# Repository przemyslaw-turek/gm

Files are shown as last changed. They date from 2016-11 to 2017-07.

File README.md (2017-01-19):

# GRANDMA MONITOR - electronic part

## I. Description
<OL>
<P style="line-height: 1cm; ">Grandma monitor is a system created to monitor conditions inside of old person's flat.
The system uses diffrent sensors to collect informations about movement, temperature etc. and send it via internet to protector. 
Main controler (Raspberry Pi 3) is connected with big red button, which turn on panic alarm (on protectors mobile device).
Except Raspberry Pi we use also ESP8266 which supports whireless communication and enables placement of sensors in the other part of the flat. </P>
</P>
<P style="line-height: 1cm; ">Befor you begin instalation you need to decide which sensors you want to use and where to put them.
Here is the list of the sensors that we support:</P>
<LI> MQ-2 Semiconductor Sensor for Combustible Gas  </LI>
<LI> PIR HC-SR501 Motion Sensor </LI>
<LI> DS18B20 Temperature Sensor </LI>
<LI> DHT11 Humidity & Temperature Sensor</LI>
<LI> Reed relay</LI>
</OL>

## II. Instalation
<OL>
<P style="line-height: 1cm; ">
The electronic part of the project is divided into three main parts:
</P>
<LI> Raspberry PI 3	(master controller) </LI>
<LI> ESP8266	(slave controller) </LI>
<LI> Sensors </LI>
<P style="line-height: 1cm; ">

</P>
<P style="line-height: 1cm; ">
In each of this parts you can find the manual.
</P>

</OL>

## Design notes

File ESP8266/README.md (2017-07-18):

<html>
<h1>#ESP8266 configuration</h1>
<li>If you are using ESP8266 with NodeMcu dev board just plug in to USB using micro USB (there is already USB to UART RS232 converter on board). If yours computer didn’t see ESP you may need to install CH340 Driver </li>
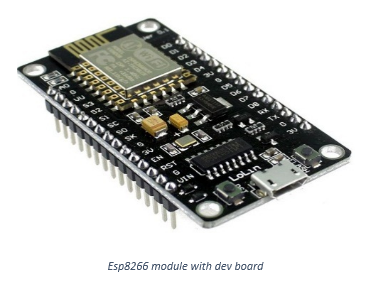
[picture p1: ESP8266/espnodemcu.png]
ESP with NodeMcu board

After that download and install Arduino IDE (at least 1.6.4 version).<br>
Create subfolder “portable” in Arduino folder. Then open File->Preferences , in Additional Boards Manager URL’s paste: <b>http://arduino.esp8266.com/stable/package_esp8266com_index.json</b><br><br>
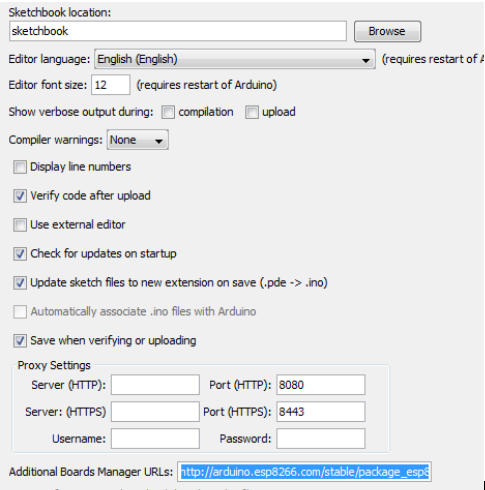
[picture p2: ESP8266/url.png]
boardmanager
<br>
<br>
Then in Tools->Board->Boards Manager install esp8266 package<br>

package<br>
<br>
To add libraries in Arduino IDE: Sketch -> Include library ->Manage libraries type the library you need and add it.<br><br>

Libraries used in project: <br>
-Adafruit<br>
-DHT<br>
-DHT_U<br>
-ESP8266WiFi<br>
-PubSubClient<br>
<br>
It is not possible to add Adafruit library to libraries in Arduino. It is need to download this library direct from Github repository. 

To upload program in Arduino  in Tools you need to choose Board (depends on ESP version, for example Generic ESP module), upload speed 115200.<br><br>

To check your connection with raspberry pi (broker) upload code from ESP8266_wifi_mqtt.ino.  <br>
For debug you can use serial monitor (Tools -> Serial monitor).

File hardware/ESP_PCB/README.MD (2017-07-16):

<b>PCB for ESP8266</font></b><br />
<br />
I. BASIC VERSION:
<br />
<br />
Necessery elements:
<br />
<ul>
<li>ESP 8266</li>
<br />
<li>7x Screw terminals 3-Pin 3,5mm - https://botland.com.pl/zlacza-ark/2555-zlacze-ark-raster-35-mm-3-pin-.html</li>
<br />
<li>Level shifter - http://allegro.pl/modul-konwerter-poziomow-3-3v-5v-stanow-log-i4973044836.html</li>
<br />
</ul>

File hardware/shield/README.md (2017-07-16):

<b>Raspberry Pi 3 Shield</font></b><br />
<br />
I. BASIC VERSION:
<br />
<br />
Necessery elements:
<br />
<ul>
<li>7x Screw terminals 3-Pin 3,5mm - https://botland.com.pl/zlacza-ark/2555-zlacze-ark-raster-35-mm-3-pin-.html</li>
<br />
<li>Female goldpin header 2x40 2,54mm - https://botland.com.pl/gniazda-szpilkowe-goldpin/1104-listwa-zeska-2x40.html</li>
<br />
<li>Level shifter - http://allegro.pl/modul-konwerter-poziomow-3-3v-5v-stanow-log-i4973044836.html</li>
<br />
</ul>

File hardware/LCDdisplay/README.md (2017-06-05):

<h1> LCD display </h1>
<h2> 1. Connection diagram</h2>
Pictrue
 
<h2> 2. Components</h2>
<ol>
<li>ESP8266 Lolin </li>
<li>Voltage converter(SPF-02259)</li>
<li>I2C converter(LCD-02352)</li>
<li>LCD display(2x16)</li>
</ol>

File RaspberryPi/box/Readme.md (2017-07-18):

<h1>Casing</h1>
File: <b>pudelko2-1.stl</b> is a three-dimensional design of the RaspberryPi microprocessor casing.
Just check the dimensioning and the file is suitable for direct 3D printing.

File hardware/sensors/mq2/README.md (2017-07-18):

<html>
<h1>#Smoke detector and flammable gases MQ-2 sensor </h1>
<li>Wiring diagram</li>
Diagram
<li>	The necessary elements</li><br>
      1.	ESP 12e nodemcu v3

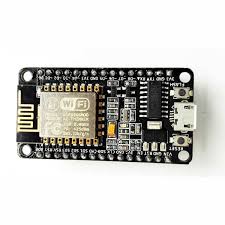
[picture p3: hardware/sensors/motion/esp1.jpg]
ESP
 <br>
 ESP<br>
      2. Bc557 NPN1<br>
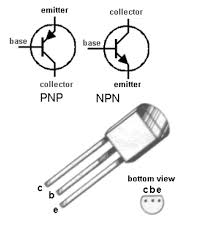
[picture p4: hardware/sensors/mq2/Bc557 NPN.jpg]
NPN
      <br>
      3. Voltage source (5V)<br>
4. MQ-2<br>
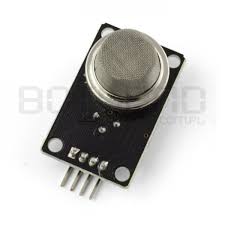
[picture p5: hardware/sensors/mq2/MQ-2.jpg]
mq2
<br>
5. Resistor(4.7kΩ)<br>
6. GPIO 14(D5)<br>
7. Wiring diagram<br>

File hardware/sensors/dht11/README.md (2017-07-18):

<html>
<h1>#Temperature and humidity sensor DHT11 </h1>
<li>Wiring diagram</li>
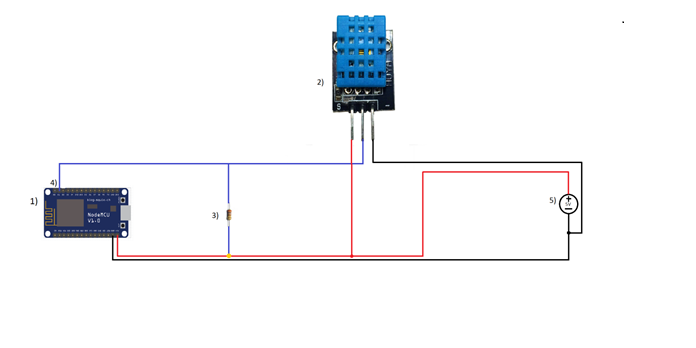
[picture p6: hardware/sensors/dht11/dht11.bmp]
Diagram

<li>	The necessary elements</li><br>
      1.	ESP 12e nodemcu v3

 ESP<br>
 ESP<br>
      2. DHT11<br>
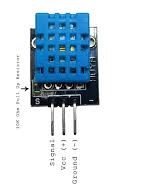
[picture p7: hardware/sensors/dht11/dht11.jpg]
DHT
      <br>
     3. Resistor 4.7kΩ <br>
      4. GPIO5(D1)  <br>
      5. Voltage source(5V)

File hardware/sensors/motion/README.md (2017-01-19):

<html>
<h1>#PIR-HC-SR501 Motion sensor </h1>
<li>Wiring diagram</li>
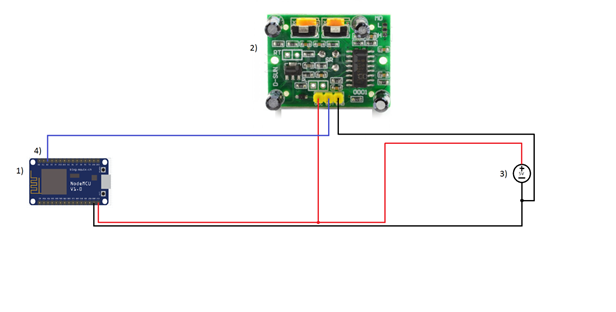
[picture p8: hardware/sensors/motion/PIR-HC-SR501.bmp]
Diagram

<li>	The necessary elements</li><br>
      1.	ESP 12e nodemcu v3

 ESP<br>
 ESP<br>
      2. PIR HC-SR501<br>
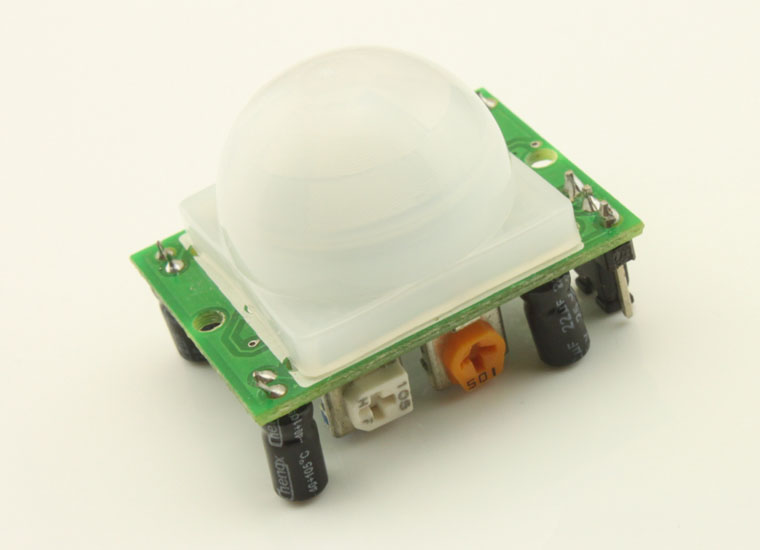
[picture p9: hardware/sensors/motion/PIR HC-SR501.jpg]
PIR
      <br>
      3.	Voltage source(5V)<br>
      4.	GPIO 4(D2)<br>

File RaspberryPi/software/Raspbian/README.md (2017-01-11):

# Installation of Raspbian 

## I. Software

#### 1. Download Raspbian:
   https://www.raspberrypi.org/downloads/raspbian/
#### 2. Download Putty:
   http://www.chiark.greenend.org.uk/~sgtatham/putty/download.html 
#### 3. Download RUFUS:
   https://rufus.akeo.ie/?locale=pl_PL 

## II. SSH Server

<OL>
<LI> Unpack file with Raspbian's image </LI>
<LI> Format microSD card </LI>
<LI><P> Use Rufus to install Raspbian on card. Use settings as in the picture below: </P>
<P> (Button in red frame is used to select the path to Raspbian's image.) </P>
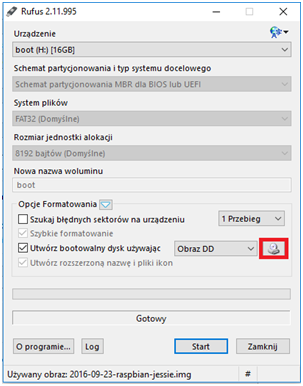
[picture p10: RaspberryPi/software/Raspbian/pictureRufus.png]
</LI> 

<LI> Press "Start". </LI>
<LI> Open your memory card and create new file "ssh" in main folder. Make sure that it hasn't got filename extension. </LI>
<LI> Place the memory card in the Raspberry </LI>
<LI> Connect Raspberry with router using ethernet cable </LI>
<LI> Connect the supply to the Raspberry </LI>
<LI><P> Check Raspberry's IP address in router </P>
Pictrue</LI>
<LI> Run Putty </LI> 
<LI> In field Host Name - type Raspberry's IP address </LI>
<LI><P> Press "Open" </P>
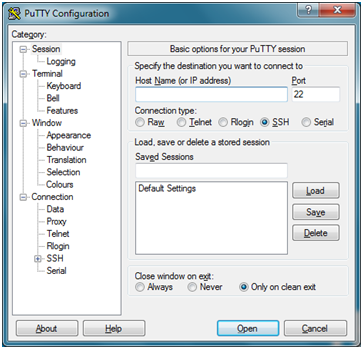
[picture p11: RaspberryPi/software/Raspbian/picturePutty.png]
</LI>
<LI><P> Press "Yes" </P>
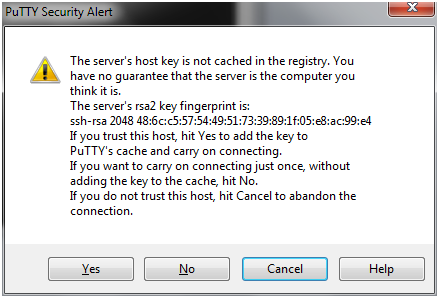
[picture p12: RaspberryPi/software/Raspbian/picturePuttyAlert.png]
</LI>
<LI><P> Default login: "pi" </P>
<P> Default password: "raspberry" </P></LI>

</OL>

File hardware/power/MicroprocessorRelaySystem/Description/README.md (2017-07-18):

Microprocessor relay system
Through this arrangement we have the ability to control devices powered by alternating current.
In order to realize this layout you have to combine elements according to the schematic.
You can prepare the chip yourself, or use a pcb board design.
Please upload to esp8266 prepared program in Arduino IDE.
If you upload a program and specify good network parameters you should get the following form of serial port monitor:
 
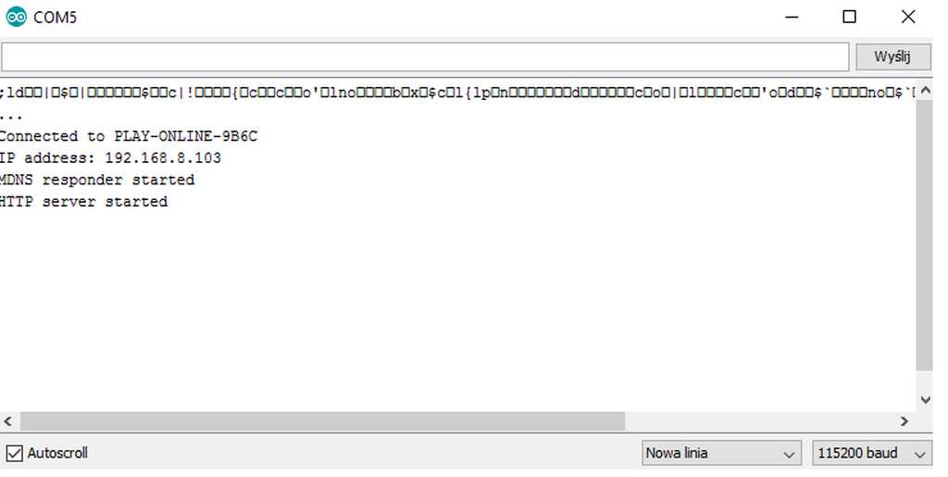
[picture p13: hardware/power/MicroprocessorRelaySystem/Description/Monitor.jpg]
 
Open the Arduino serial monitor at a baud rate of 115200. 
After a few seconds your IP address should appear.

Open any browser from a device that is connected to the same router that your ESP is. Then type the IP address and click Enter!

You should see the following image:
 
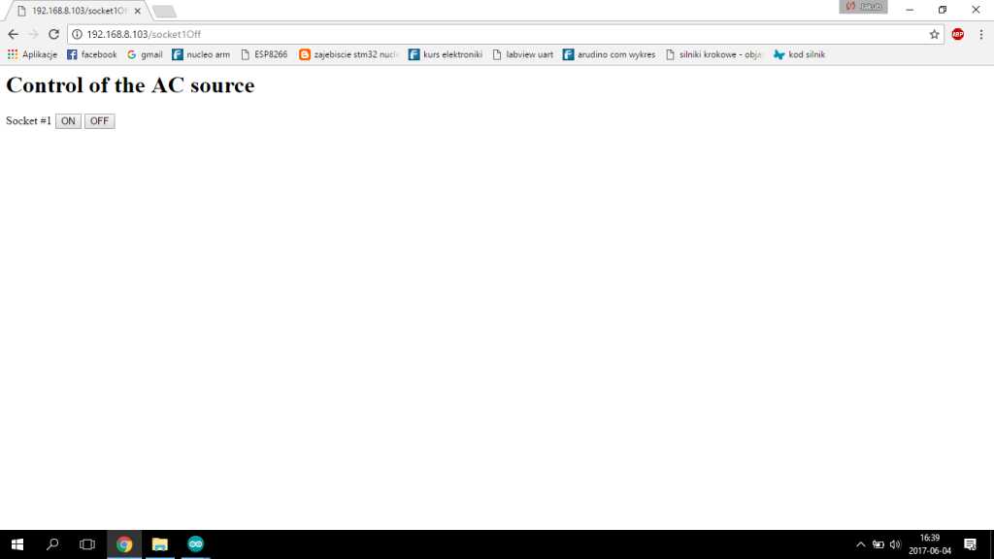
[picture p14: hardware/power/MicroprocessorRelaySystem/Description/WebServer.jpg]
 
Now when you press the buttons in your web server you can control any device connected!!!

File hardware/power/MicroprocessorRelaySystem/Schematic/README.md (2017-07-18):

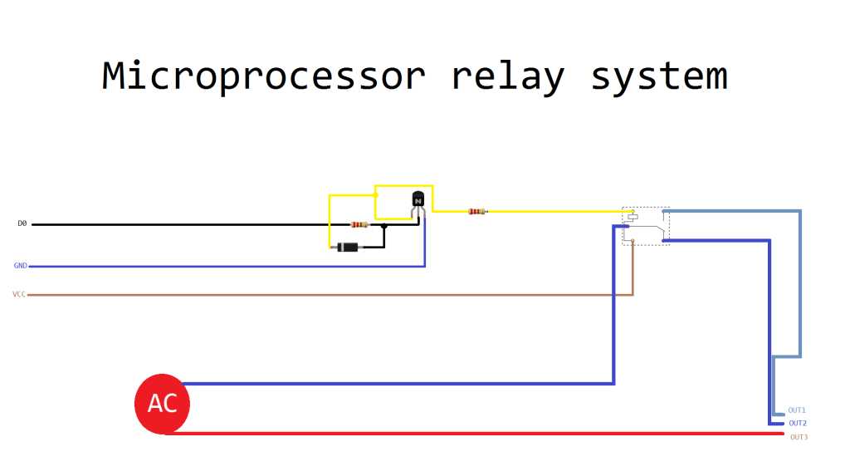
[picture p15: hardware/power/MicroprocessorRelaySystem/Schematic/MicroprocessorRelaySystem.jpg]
Pictrue
  
<li>Components</li>

1. ESP8266 Lolin
2. Transistor npn(C3274D)
3. Relays(36.11-4011)
4. Diode(4007)
5. Resistor 220 Ohm
6. Resistor 
7.Screw connection
 
 VCC and GND for 3,3V voltage;
 AC- Sinusoidal power supply

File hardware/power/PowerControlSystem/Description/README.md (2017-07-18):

<h1>Power Control System</h1>
This chip was created to make our microprocessor powered at all times. In case of power failure, the system should be powered from Power Bank. When Power bank is charging does not give the output voltage.

You need to do one of three layouts. The first one is easier to implement and the second one does not disturb the operation of the control device. The third circuit is the simplest and does not use ADC.
The fourth system is designed for advanced electronics. For this layout we have not prepared the program code. It is shown for illustrative purposes

<b>If you use the third  chip, you will need to use 0 GPIO to control the power supply!!!!</b>

If you use the first chip, you will need to use 3 GPIO to control the power supply(A0,D5 and D6).

In turn, using the second scheme will suffice with two pins(A0 and D5).

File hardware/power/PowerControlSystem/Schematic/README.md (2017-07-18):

<u><h1><b>&nbsp;&nbsp;&nbsp;&nbsp;&nbsp;&nbsp;&nbsp;&nbsp;&nbsp;&nbsp;&nbsp;&nbsp;&nbsp;&nbsp;&nbsp;&nbsp;&nbsp;&nbsp;&nbsp;&nbsp;&nbsp;&nbsp;&nbsp;&nbsp;&nbsp;&nbsp;&nbsp;&nbsp;&nbsp;&nbsp;&nbsp;&nbsp;Power control system</b></h1></u>

<b>I version</b>

<li>Connection diagram</li>

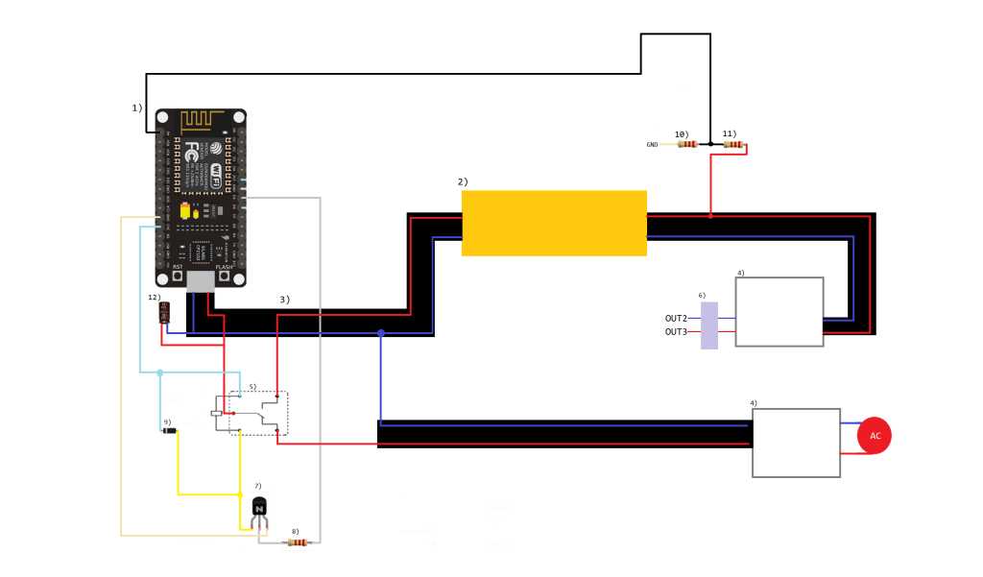
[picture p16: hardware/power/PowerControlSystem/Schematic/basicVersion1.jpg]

 
<li>Components</li>

1. ESP8266 Lolin					
2. Power bank(5V)					
3. USB cable						
4. Power supply					
5. Relay(3.3-5V)
6. Screw connection
7. Transistor npn(C3274D)
8. Resistor(100 Ohm)
9.   Diode(4007)
10. Resistor(2200 Ohm)
11. Resistor(1200 Ohm)
13. Electrolytic capacitor(47 uF)

<b>II version</b>

<li>Connection diagram</li>

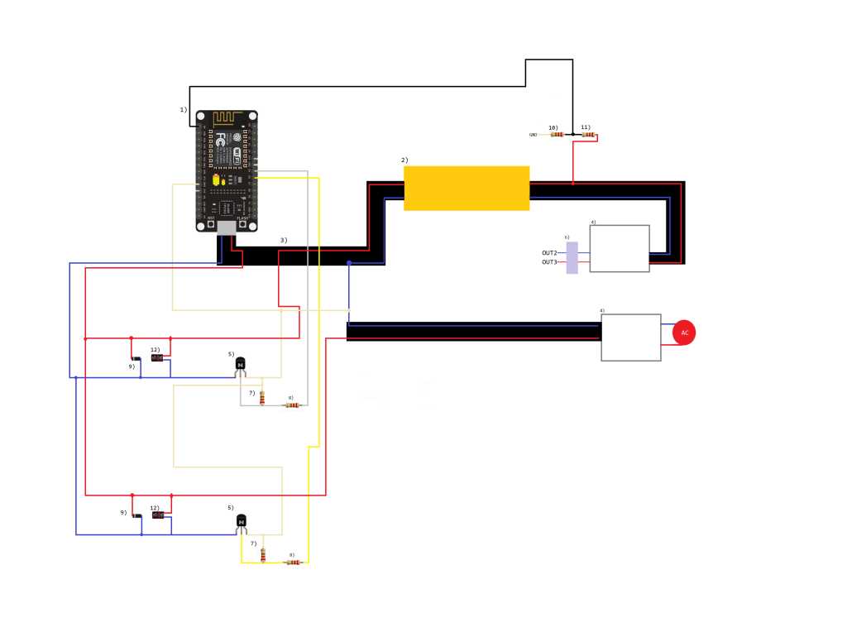
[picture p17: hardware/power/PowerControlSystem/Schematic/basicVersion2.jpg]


<li>Components</li>

1. ESP8266 Lolin					
2. Power bank(5V)					
3. USB cable						
4. Power supply					
5. Transistor npn(C3274D) 
6. Screw connection
7. Resistor( 2200 Ohm)
8. Resistor( 100 Ohm)
9.   Diode(4007)
10. Resistor(2200  Ohm)
11. Resistor(1200 Ohm)
12. Electrolytic capacitor(47 uF)

<b>III version</b>

<li>Connection diagram</li>

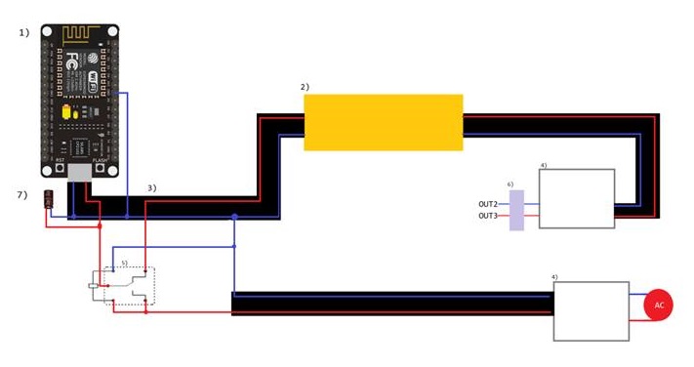
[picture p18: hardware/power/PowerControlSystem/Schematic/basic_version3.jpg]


<li>Components</li>

1. ESP8266 Lolin					
2. Power bank(5V)					
3. USB cable						
4. Power supply			
5. Relay(3.3-5V)
6. Screw connection
7. Electrolytic capacitor(47 uF)

<b>IV version</b>

<i>Extended version</i>

<li>Connection diagram</li>

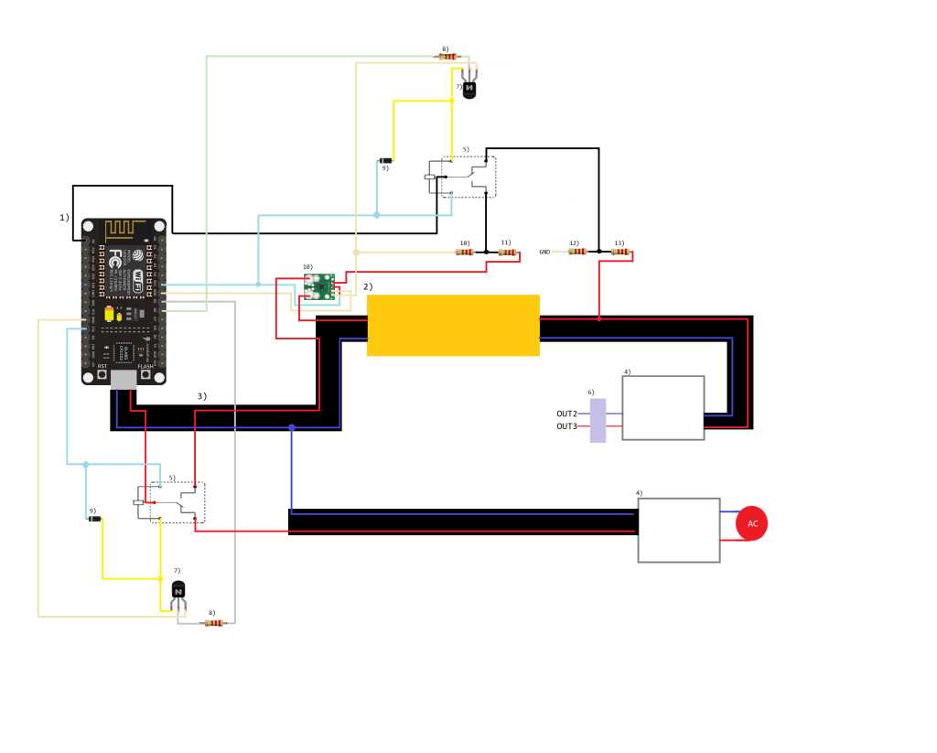
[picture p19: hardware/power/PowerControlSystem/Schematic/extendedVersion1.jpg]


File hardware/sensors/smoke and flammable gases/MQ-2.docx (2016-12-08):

Smoke detector and flammable gases

1) Wiring diagram

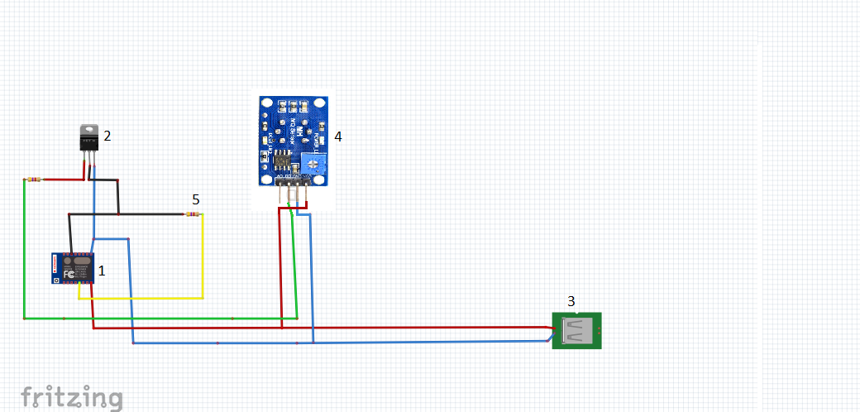
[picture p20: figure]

2) The necessary elements

1. ESP 12e nodemcu v3

2. Bc557 NPN

3. USB (5V)

4. MQ-2

5. Resistor(4.7kΩ)

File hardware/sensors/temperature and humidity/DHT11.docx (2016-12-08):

Temperature and humidity sensor

1) Wiring diagram

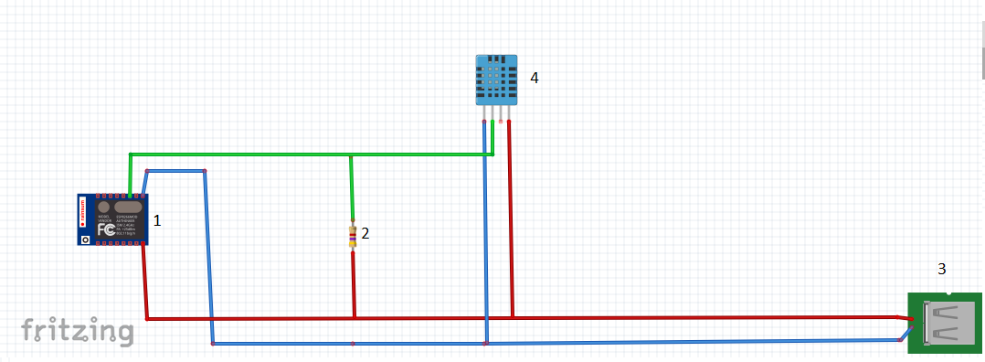
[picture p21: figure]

2) The necessary elements

1. ESP 12e nodemcu v3

2. Resistor 4.7kΩ

3. USB (5V)

4. DHT11

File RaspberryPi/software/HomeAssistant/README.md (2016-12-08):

# Installation of Home Assistant

## I. Installation

<OL>
<LI> Type in Putty's terminal: </LI>

<P> sudo apt-get update </P>

<P> sudo apt-get upgrade -y </P>

<P> sudo pip3 install homeassistant </P>

<P> Command(below) runs file configuration.yaml and Raspberry's communication with Home Assistant </P>

<P> hass </P>

</OL>

## II. Verification of installation correctness 
<OL>
<LI><P> Type in Putty's terminal: </P></LI>
<P>	hass </P>
<LI>Wait for communicate in Putty's terminal like this: </LI>

<P> INFO:homeassistant.core:Bus:Handling Event state_changed[L]:... </P>

<LI> Type in the Web browser: </LI>
<P>	http://ipaddress:8123 </P>

<P>	For example: http://192.168.1.106:8123 </P>

<LI> Press "Enter" </LI>
<P> If everything works, you should see in the Web browser screen like this: </P>
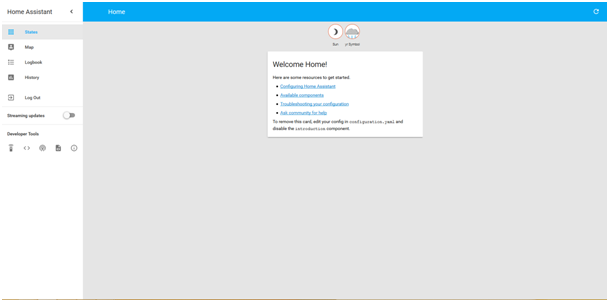
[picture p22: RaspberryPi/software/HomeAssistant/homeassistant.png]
 

<LI>Press "Ctrl" + "c" to close Raspberry's communication with Home Assistant (Sometimes, you have to press it twice) </LI>
</OL>

# Configuration of Home Assistant

## I. Configuration.yaml file upload

<OL>
<LI><P> Type in Putty's terminal: </P></LI>
<P> cd /home/pi/.homeassistant </P>
<P>	rm configuration.yaml </P>
<P> nano configuration.yaml </P>

<P> And now you should see picture like this: </P>
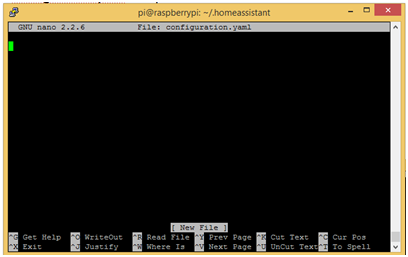
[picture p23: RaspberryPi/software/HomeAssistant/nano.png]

	
<LI> Copy the text from "configuration.yaml" (pay attention to spaces and tabs) and paste in this black screen in Putty's terminal
It should looks like this picture (below): </LI>
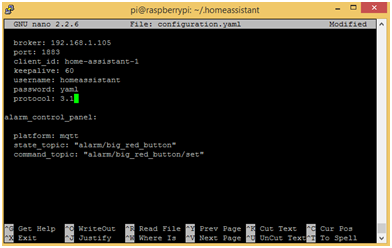
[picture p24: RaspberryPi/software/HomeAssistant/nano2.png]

 
 <LI> Change broker's IP for MQTT in configuration.yaml in the same what is using to Putty's communications  </LI>
<LI> Press "Ctrl" + "X" </LI>
<LI> Press "Y" </LI>
<LI> Press "Enter" </LI>	
<LI> Type in Putty's terminal: 

<P> hass </P></LI>
</OL>

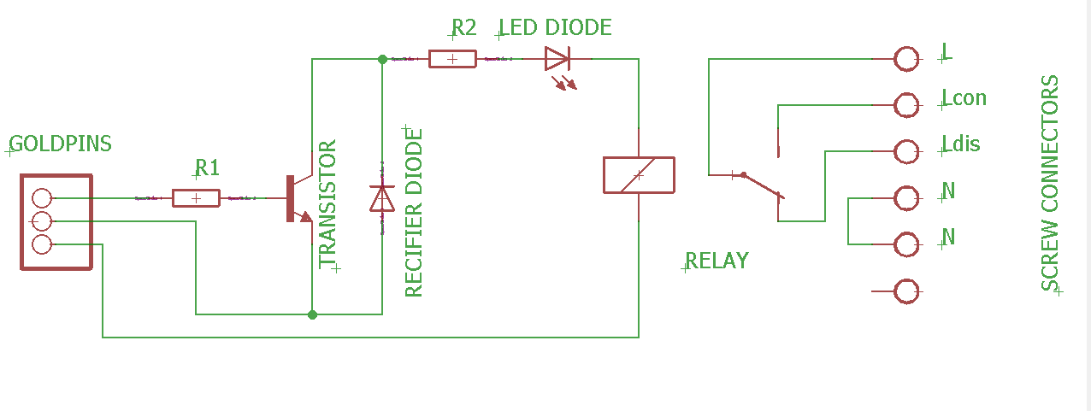
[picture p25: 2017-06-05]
hardware/power/MicroprocessorRelaySystem/PCB/sch.PNG

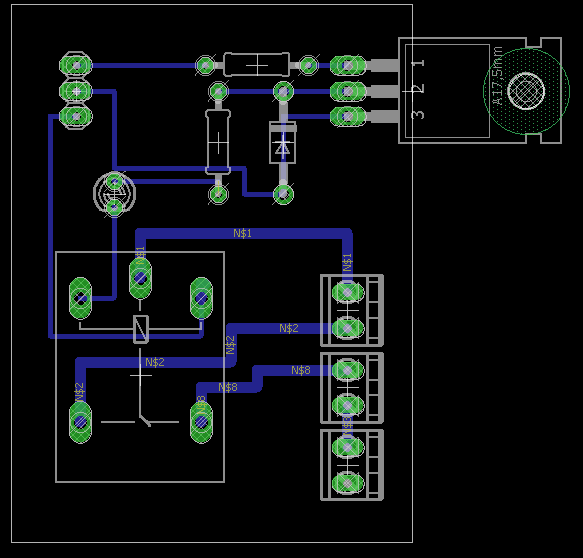
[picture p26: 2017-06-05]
hardware/power/MicroprocessorRelaySystem/PCB/brd.PNG

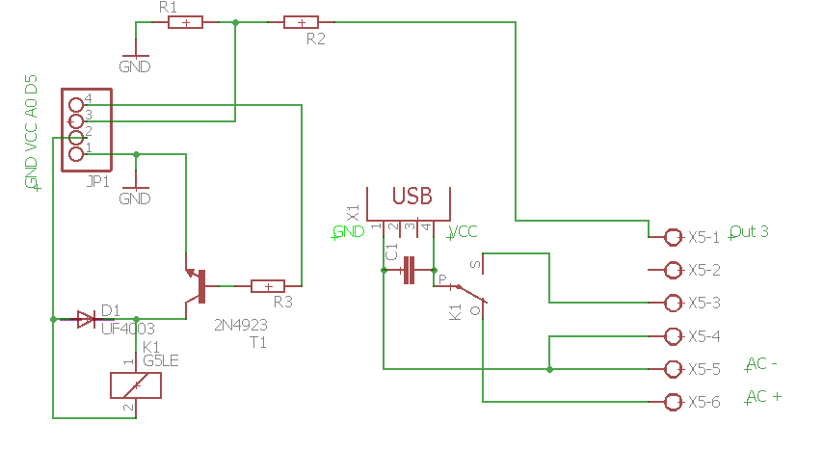
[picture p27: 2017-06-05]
hardware/power/PowerControlSystem/PCB/sch.PNG

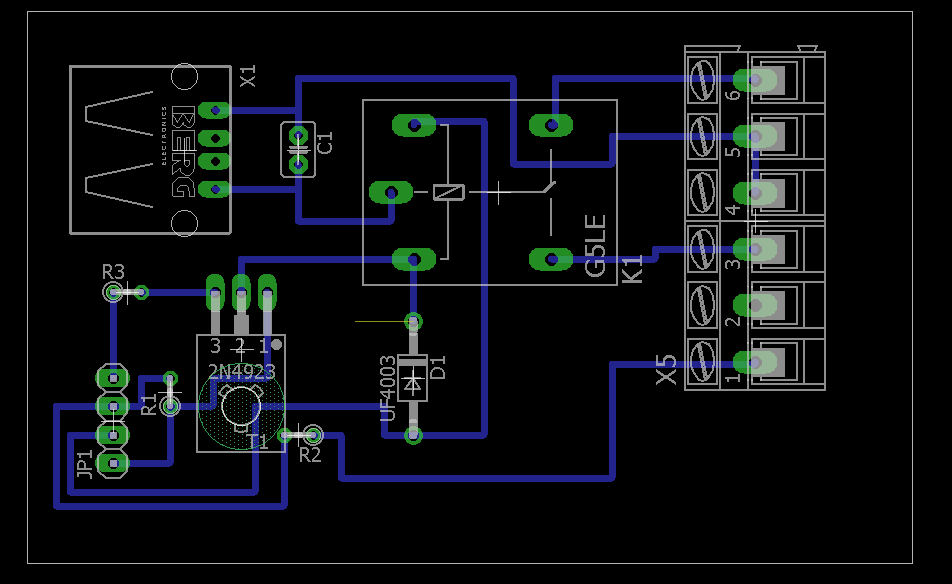
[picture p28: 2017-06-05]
hardware/power/PowerControlSystem/PCB/brd.PNG

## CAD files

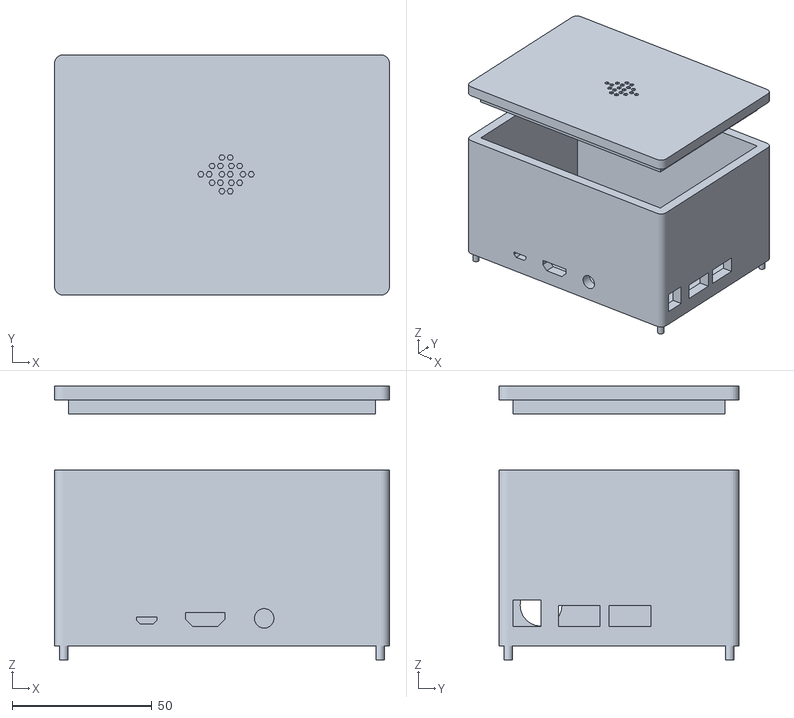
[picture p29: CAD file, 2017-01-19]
RaspberryPi/box/pudelko2-1.stl
120.0 x 86.0 x 98.0

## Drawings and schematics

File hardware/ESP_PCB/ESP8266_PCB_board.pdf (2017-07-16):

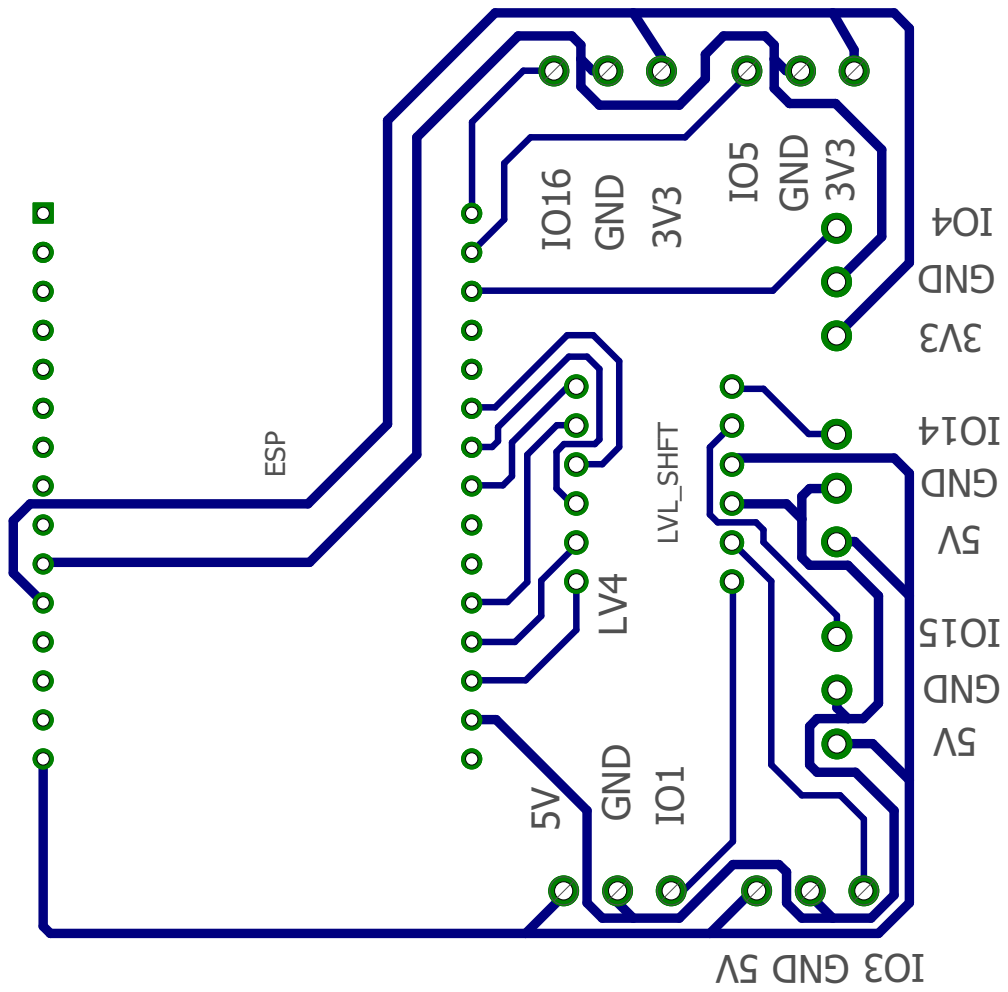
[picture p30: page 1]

5V V5 V5V5 DNG DNG GND GND DNG DNG GND IO16 3V33V3 3V3 IO5 4 OI 41 OI 51 OI 3 OI IO1 LV4 ESP LVL_SHFT

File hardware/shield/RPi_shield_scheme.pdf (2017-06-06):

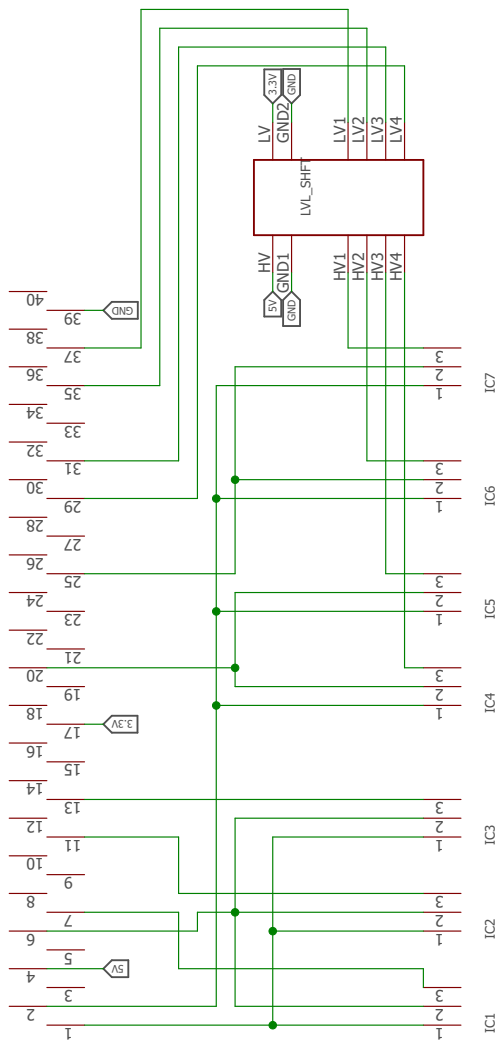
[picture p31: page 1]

1 2 3 4 5 6 7 8 9 01 11 21 31 41 51 61 71 81 91 02 12 22 32 42 52 62 72 82 92 03 13 23 33 43 53 63 73 83 93 04 123 IC1 123 IC2 123 IC3 123 IC4 123 IC5 123 IC6 123 IC7 HV1 HV2 HV3 HV4 LV1 LV2 LV3 LV4 HV LV GND1 GND2 LVL_SHFT DNG GND GND 3.3V V3. 3 5V V5

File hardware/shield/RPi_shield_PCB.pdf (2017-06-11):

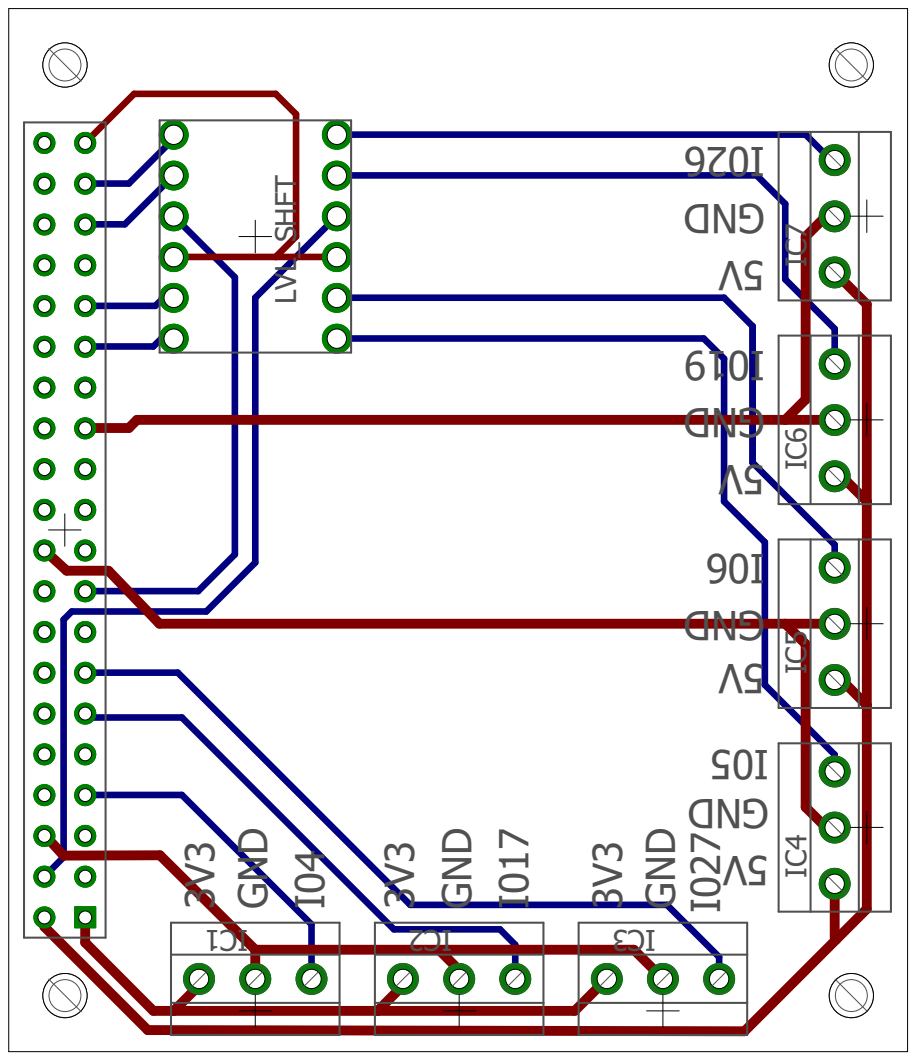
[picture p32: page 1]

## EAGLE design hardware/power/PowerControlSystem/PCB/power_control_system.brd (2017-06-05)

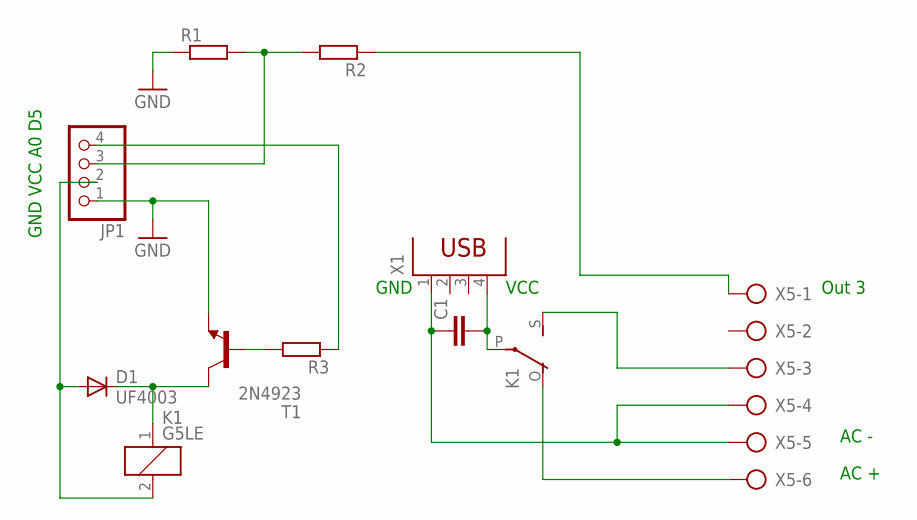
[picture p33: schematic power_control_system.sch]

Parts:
C1: C2,5-3; C2.5-3
D1: UF4003; DO41-10
JP1: PINHD-1X4; 1X04
K1: G5LE
R1, R2, R3: R-EU_0204/2V; 0204V
T1: 2N4923; TO126
X1: PN87520
X5: AK300/6

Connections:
GND: JP1.1, R1.1, T1.1 (E)
unnamed: JP1.3, R1.2, R2.2
unnamed: JP1.4, R3.1
unnamed: R3.2, T1.3 (B)
unnamed: D1.C, K1.1, T1.2 (C)
unnamed: D1.A, JP1.2, K1.2
unnamed: C1.1, X1.1, X5.4, X5.5
unnamed: C1.2, K1.P, X1.4
unnamed: K1.O, X5.6
unnamed: K1.S, X5.3
unnamed: R2.1, X5.1

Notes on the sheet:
GND VCC A0 D5
GND
VCC
AC +
AC -
Out 3

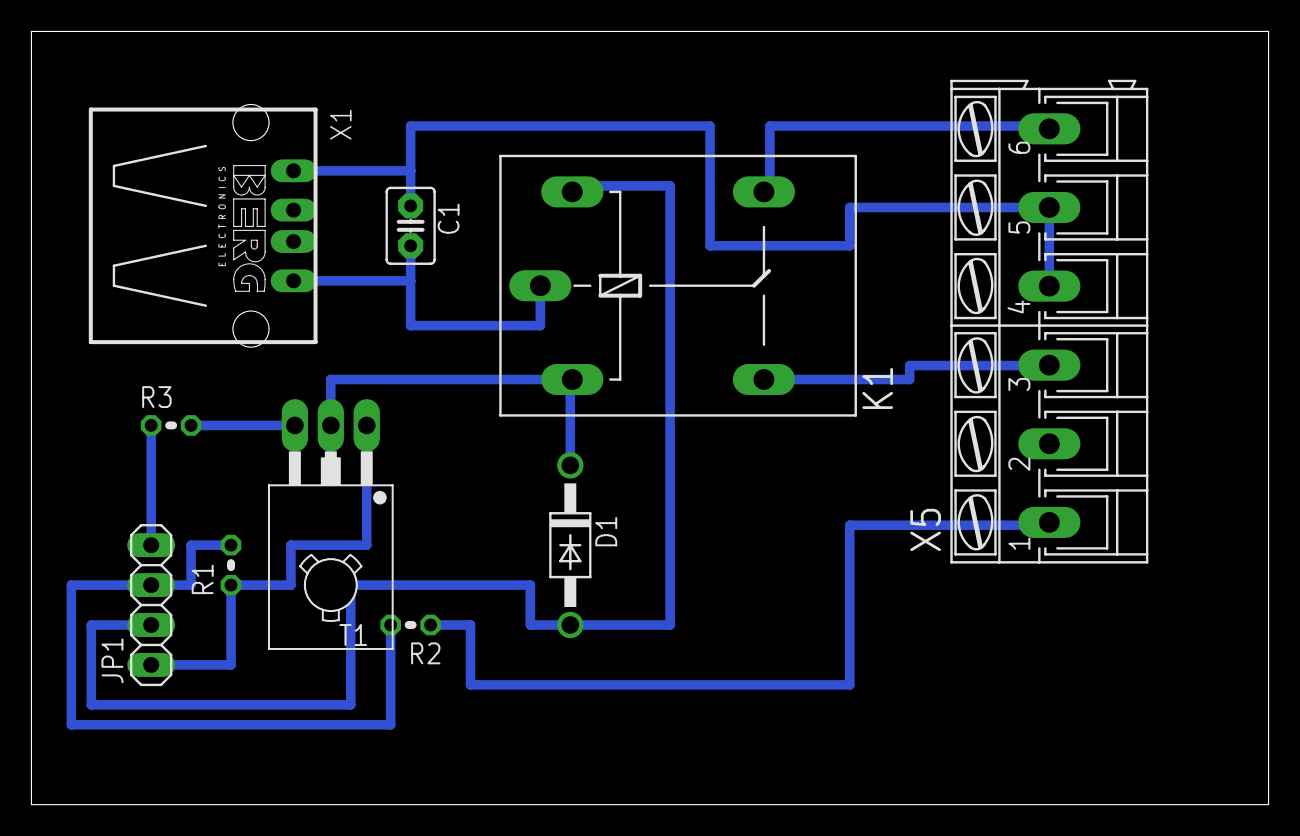
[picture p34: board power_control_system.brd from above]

Board: 2 copper layers, 78.7 x 49.2 mm, 10 parts (0 on the bottom side), 11 nets.

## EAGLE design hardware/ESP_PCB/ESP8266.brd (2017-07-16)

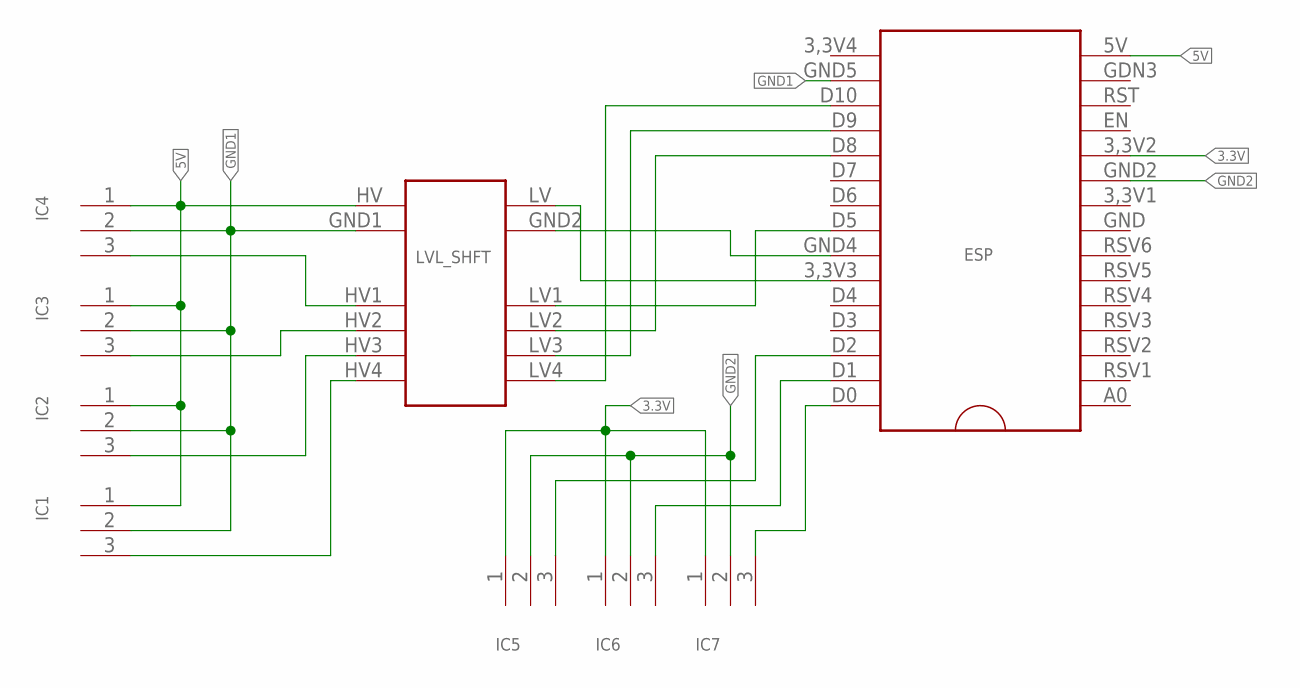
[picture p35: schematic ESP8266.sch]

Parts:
ESP: ESP8266_NODEMCUV2; ESP8266_NODEMCV2
IC1, IC2, IC3, IC4, IC5, IC6, IC7: 3,5MM_3PIN
LVL_SHFT: LVL_SHIFTER_4CH

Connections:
3.3V: ESP.3,3V2, IC5.1, IC6.1, IC7.1
5V: ESP.5V, IC1.1, IC2.1, IC3.1, IC4.1, LVL_SHFT.HV
GND1: ESP.GND5, IC1.2, IC2.2, IC3.2, IC4.2, LVL_SHFT.GND1
GND2: ESP.GND2, IC5.2, IC6.2, IC7.2
unnamed: IC4.3, LVL_SHFT.HV1
unnamed: IC3.3, LVL_SHFT.HV2
unnamed: IC2.3, LVL_SHFT.HV3
unnamed: IC1.3, LVL_SHFT.HV4
unnamed: ESP.D5, LVL_SHFT.LV1
unnamed: ESP.D8, LVL_SHFT.LV2
unnamed: ESP.D9, LVL_SHFT.LV3
unnamed: ESP.D0, IC7.3
unnamed: ESP.GND4, LVL_SHFT.GND2
unnamed: ESP.D10, LVL_SHFT.LV4
unnamed: ESP.3,3V3, LVL_SHFT.LV
unnamed: ESP.D2, IC5.3
unnamed: ESP.D1, IC6.3

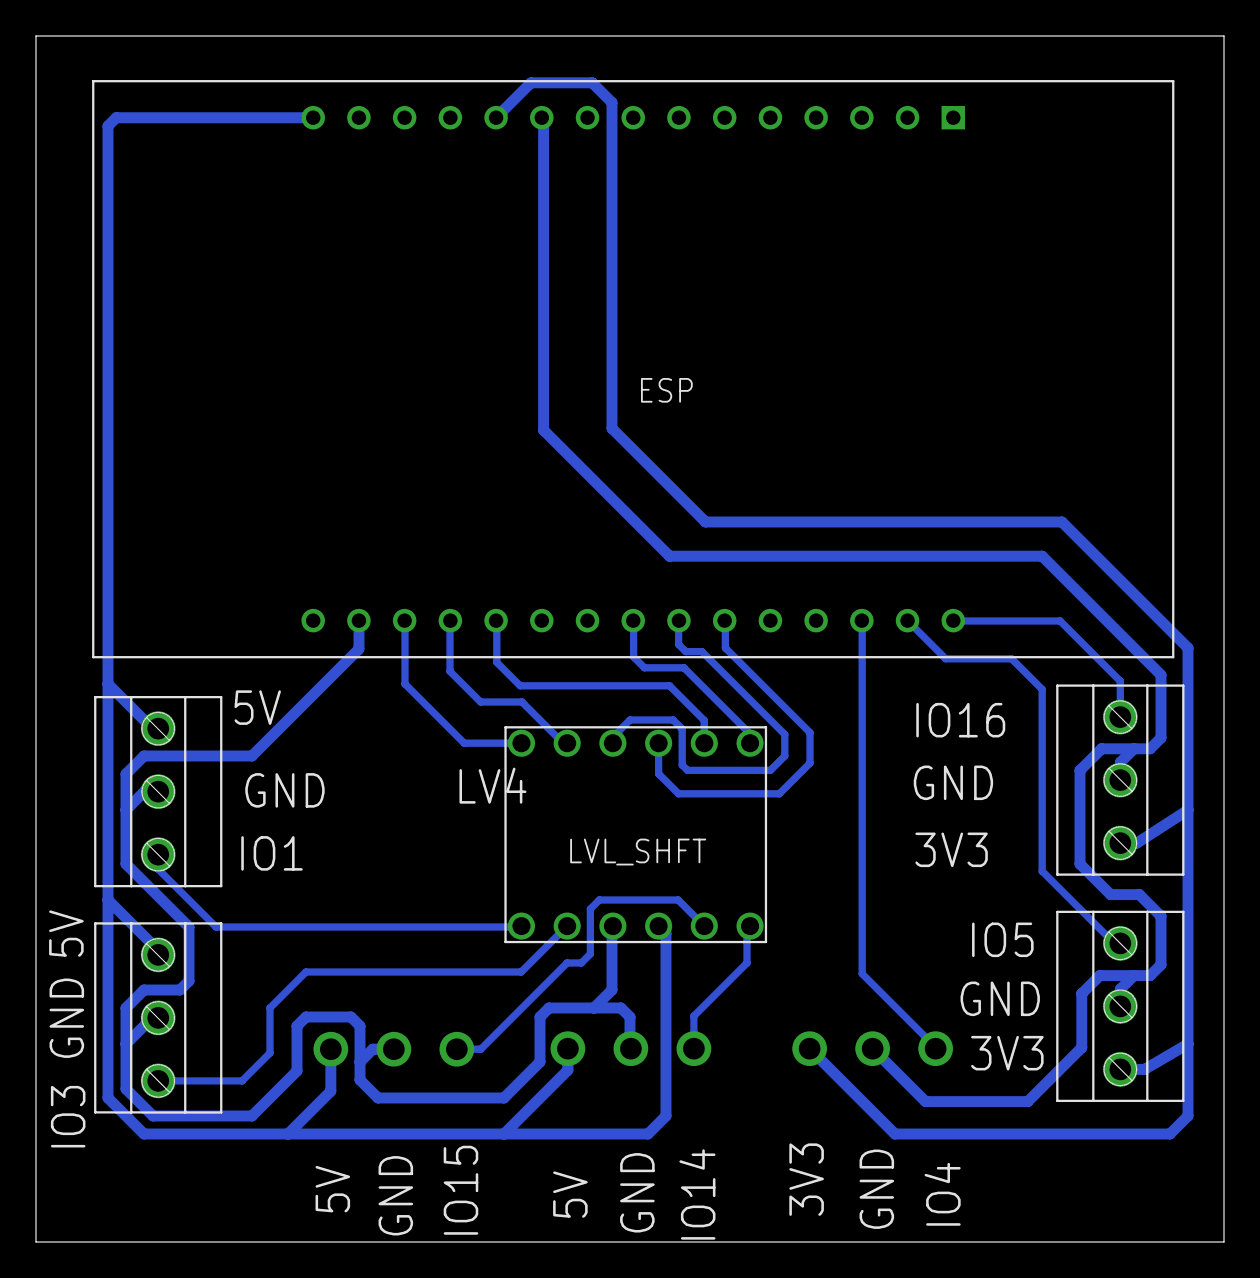
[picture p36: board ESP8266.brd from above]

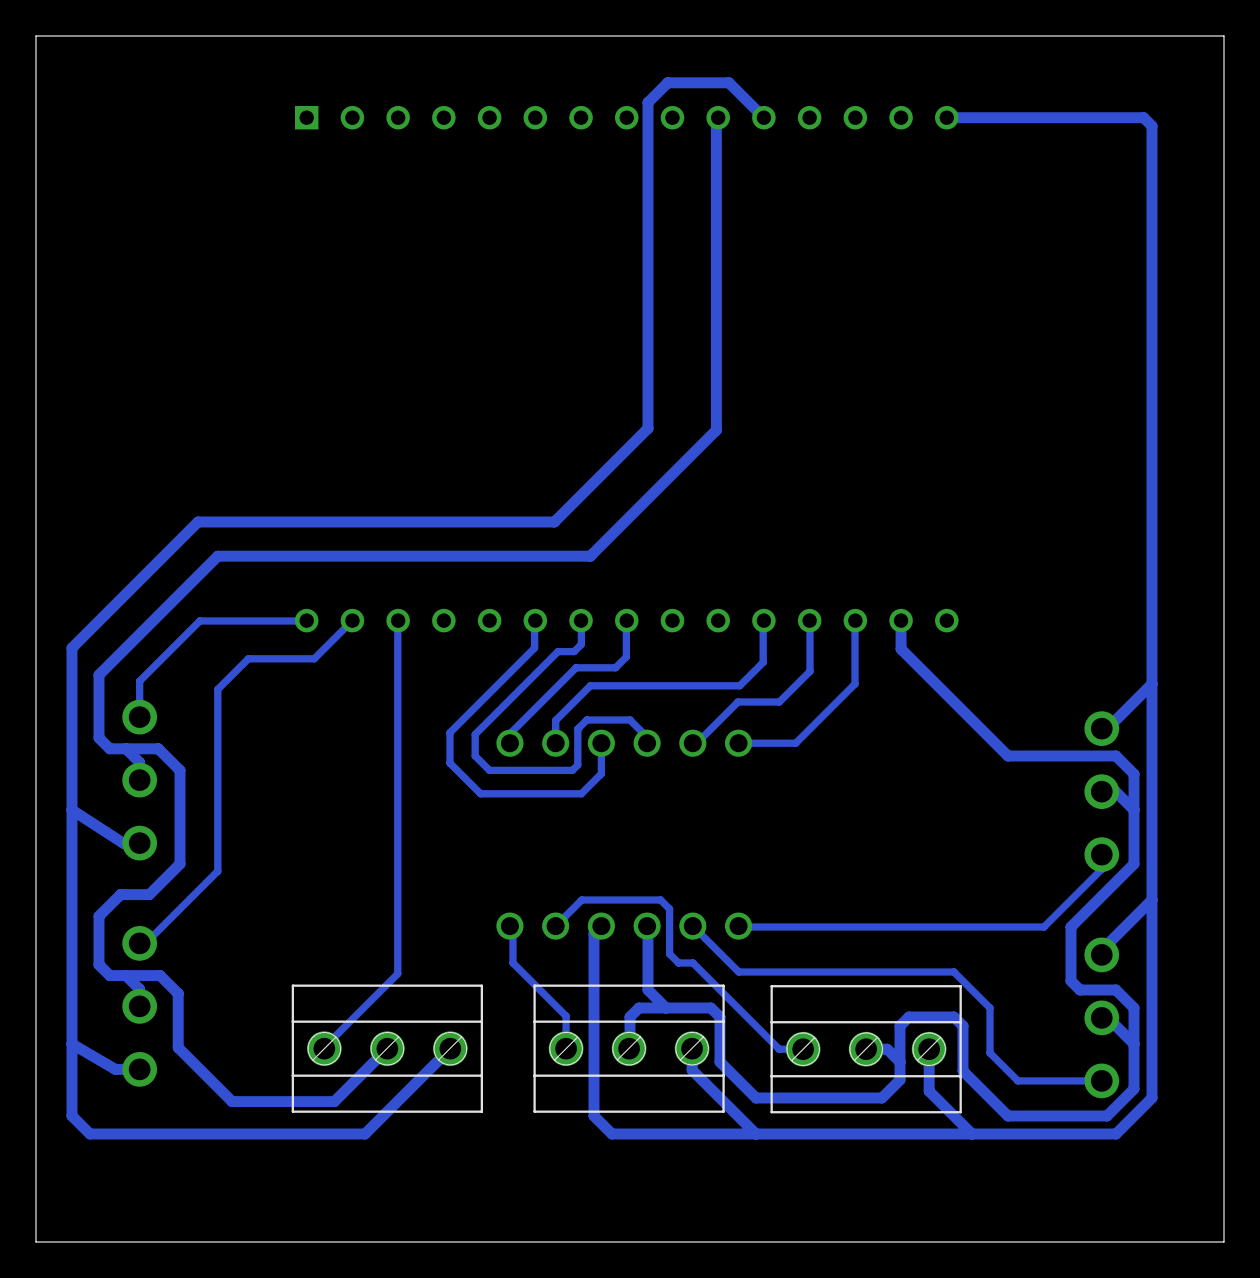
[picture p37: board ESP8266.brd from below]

Board: 2 copper layers, 66.0 x 67.0 mm, 9 parts (3 on the bottom side), 17 nets.

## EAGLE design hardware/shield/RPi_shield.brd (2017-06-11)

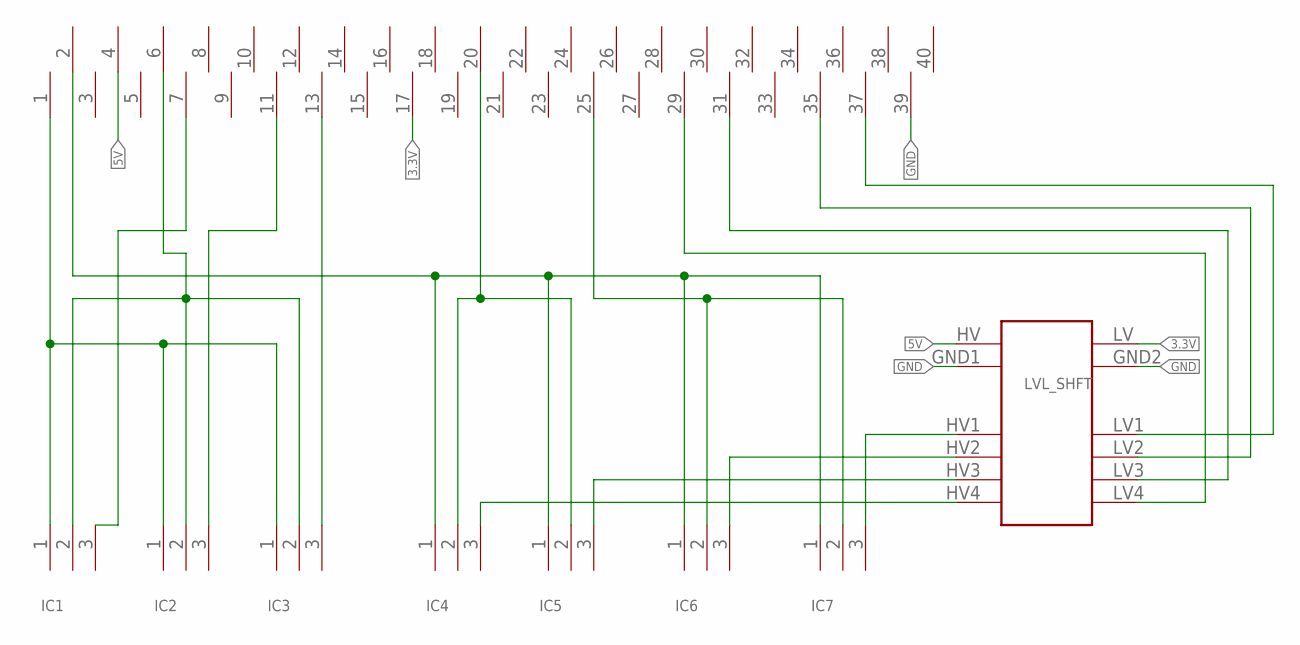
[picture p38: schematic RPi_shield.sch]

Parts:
IC1, IC2, IC3, IC4, IC5, IC6, IC7: 3,5MM_3PIN
IC17: 40_PIN_2.54MM
LVL_SHFT: LVL_SHIFTER_4CH

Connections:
3.3V: IC17.17, LVL_SHFT.LV
3.3V2: IC1.1, IC2.1, IC3.1, IC17.1
5V: IC17.4, LVL_SHFT.HV
GND: IC17.39, LVL_SHFT.GND1, LVL_SHFT.GND2
unnamed: IC4.1, IC5.1, IC6.1, IC7.1, IC17.2
unnamed: IC1.2, IC2.2, IC3.2, IC17.6
unnamed: IC4.2, IC5.2, IC17.20
unnamed: IC6.2, IC7.2, IC17.25
unnamed: IC7.3, LVL_SHFT.HV1
unnamed: IC6.3, LVL_SHFT.HV2
unnamed: IC5.3, LVL_SHFT.HV3
unnamed: IC4.3, LVL_SHFT.HV4
unnamed: IC17.37, LVL_SHFT.LV1
unnamed: IC17.35, LVL_SHFT.LV2
unnamed: IC17.31, LVL_SHFT.LV3
unnamed: IC17.29, LVL_SHFT.LV4
unnamed: IC1.3, IC17.7
unnamed: IC2.3, IC17.11
unnamed: IC3.3, IC17.13

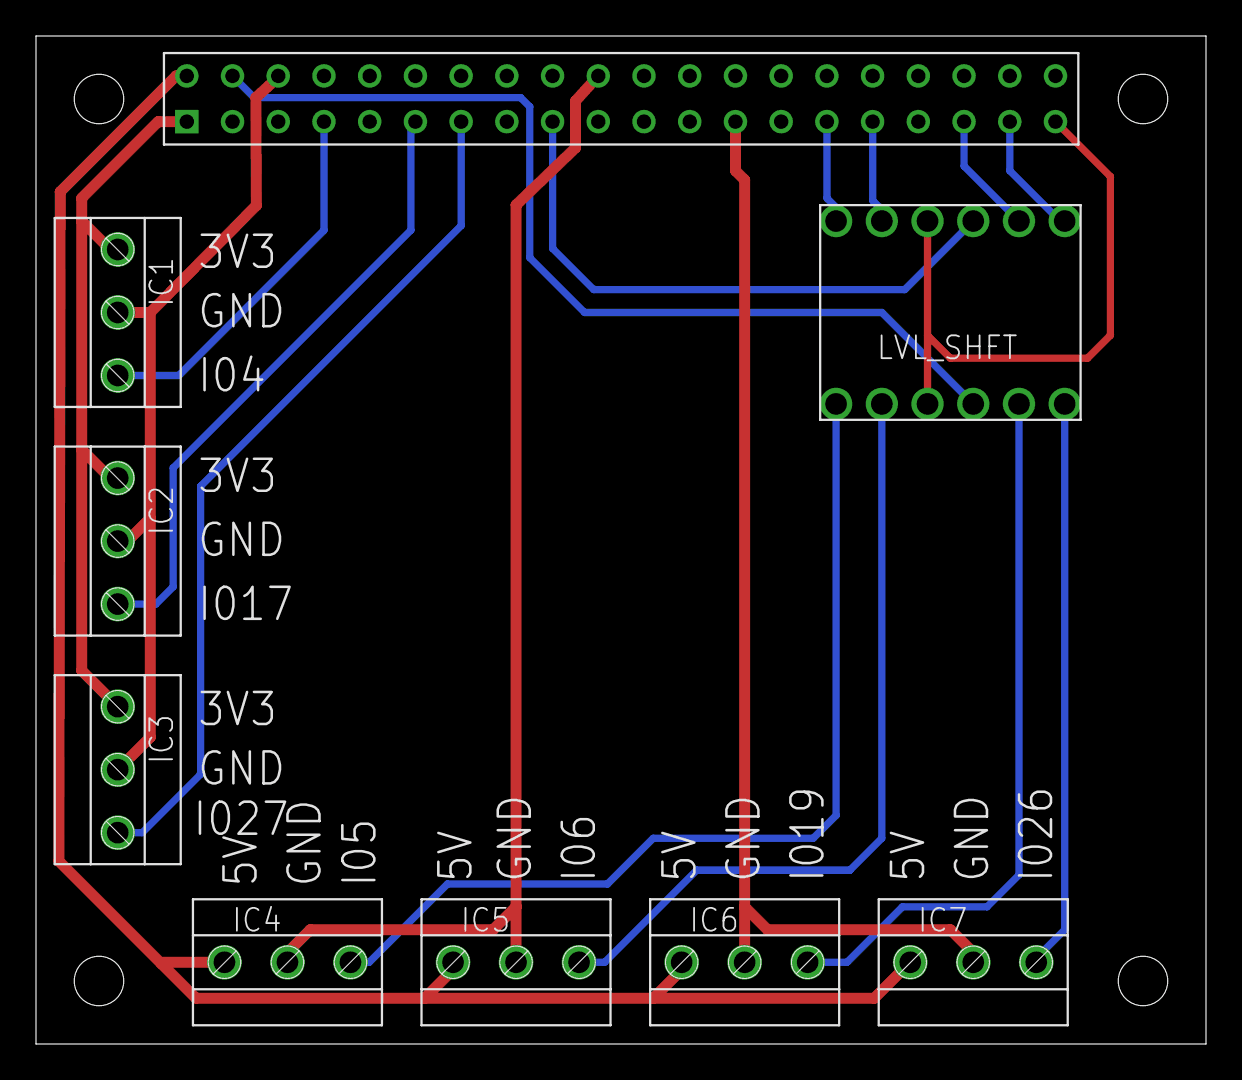
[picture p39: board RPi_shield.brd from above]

Board: 2 copper layers, 65.0 x 56.0 mm, 9 parts (0 on the bottom side), 19 nets.

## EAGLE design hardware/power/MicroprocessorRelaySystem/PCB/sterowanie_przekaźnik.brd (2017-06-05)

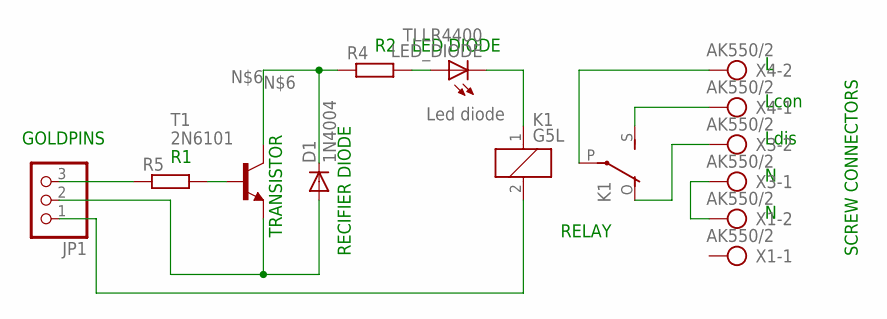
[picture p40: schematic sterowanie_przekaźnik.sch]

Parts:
D1: 1N4004; DO41-10
JP1: PINHD-1X3; 1X03
K1: G5L; G5LE
LED_DIODE: TLLR4400; LED3MM
R4, R5: R0207/10; 0207/10
T1: 2N6101; TO220
X1, X3, X4: AK550/2

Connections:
unnamed: K1.P, X4.2
unnamed: K1.S, X4.1
unnamed: X1.2, X3.1
unnamed 3: K1.1, LED_DIODE.K (C); also elsewhere on the board
unnamed: JP1.3, R5.1
unnamed: D1.C, R4.1, T1.2 (C)
unnamed: D1.A, JP1.2, T1.3 (E)
unnamed: K1.O, X3.2
unnamed: JP1.1, K1.2
unnamed: R5.2, T1.1 (B)
unnamed 10: LED_DIODE.A, R4.2; also elsewhere on the board

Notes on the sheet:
RECIFIER DIODE
GOLDPINS
LED DIODE
TRANSISTOR
RELAY
SCREW CONNECTORS
Lcon
Ldis

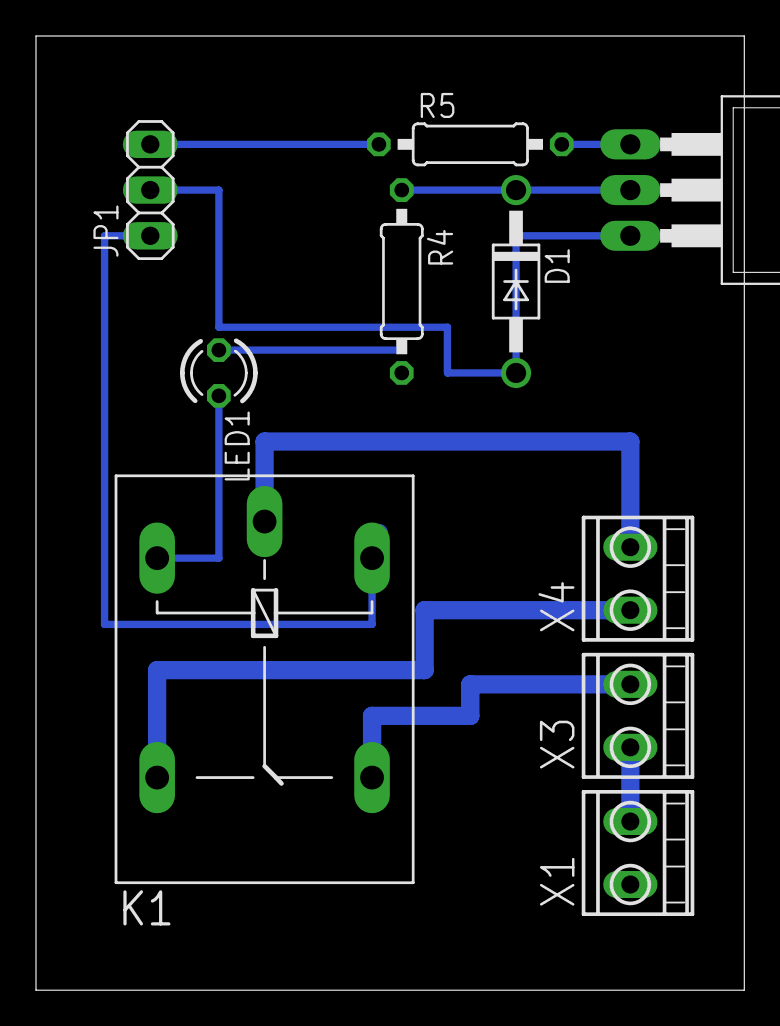
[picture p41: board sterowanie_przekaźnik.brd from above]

Board: 2 copper layers, 39.4 x 53.0 mm, 10 parts (0 on the bottom side), 11 nets.

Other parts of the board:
LED1: TLLR4400; LED3MM

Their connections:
unnamed 3: LED1.K; also elsewhere on the board
unnamed 10: LED1.A; also elsewhere on the board

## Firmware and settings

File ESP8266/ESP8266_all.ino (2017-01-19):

#include <ESP8266WiFi.h>
#include <PubSubClient.h>
#include <DHT.h>
#include <Adafruit_Sensor.h>
#include <DHT_u.h>
#include <OneWire.h>
#include <DallasTemperature.h>

// Here user can modify parameters
#define debug                                // If defined debug mode
#define DHTtime     10                           // In seconds
#define DStime      5
#define Motiontime  15

#define DHT_11                  `
#define DS_18B20         
#define PIR            
#define REEDRELAY      
#define MQ2            

#define mqtt_user "admin"                    // MQTT user ID
#define mqtt_password "admin"                // MQTT password

#define DHTTYPE                 DHT11				 // DHT 11 (type of sensor)
#define DHTPIN                  5					 // PIN connected to  DHT sensor (temperature and humidity)
#define MSPIN                   4					 // PIN connected to  motion sensor
#define MQ2PIN                  14				 // PIN connected to  MQ-2 sensor (gas sensor)
#define REEDPIN                 0
#define REEDOUT                 13 
#define ONE_WIRE_BUS            12
#define TEMPERATURE_PRECISION   9

const char* ssid = "ssid";           // your WIFI SSID (name)
const char* password = "password";         // your WIFI password
const char* mqtt_server = "192.168.0.101";   // your broker's IP (Raspberry PI 3)

//Do not modify:

// Topic's names
const char* outTopic1 = "DHT11_temperature";
const char* outTopic2 = "DHT11_humidity";
const char* outTopic3 = "PIR_motion";
const char* outTopic4 = "MQ2_gas";
const char* outTopic5 = "Reedrelay_doors";
const char* outTopic6 = "DS18B20_temperature";

float temperature;
float humidity;
int flag_th=0;
int flag_reed=0;
int flag_ds=0;
int flag_motion=0;


int state_MS;
int prev_state_MS=LOW; 	

int state_MQ2;
int prev_state_MQ2; 

int reed_counter=0;

float temp;


WiFiClient espClient;
PubSubClient client(espClient);
DHT_Unified dht(DHTPIN, DHTTYPE);
OneWire oneWire(ONE_WIRE_BUS);
DallasTemperature DS18B20(&oneWire);


void timer_interrupt (void)
{
       timer0_write(ESP.getCycleCount() + 80000000);
       flag_th++;;
       flag_reed++;
       flag_ds++;
       flag_motion++;
}

void setup_wifi()
{
	delay(10);
	// Connecting to a WiFi network

	#ifdef debug
	Serial.println();
	Serial.print("Connecting to ");
	Serial.println(ssid);
	#endif
	WiFi.begin(ssid, password);
	while (WiFi.status() != WL_CONNECTED)
	{
		#ifdef debug
		Serial.print(".");
		delay (100);
		#endif
	}
	#ifdef debug
	Serial.println("");
	Serial.println("WiFi connected");
	Serial.println("IP address: ");
	Serial.println(WiFi.localIP());
	#endif
}

void mqttconnection()
{
	// Loop until we're reconnected
	while (!client.connected())
	{
		#ifdef debug
		Serial.print("Attempting MQTT connection...");
		// Attempt to connect
                #endif
		if (client.connect("ESP8266Client", mqtt_user, mqtt_password))
		{
                        #ifdef debug
			Serial.println("connected");
                        #endif
		}
		else
		{
                        #ifdef debug
			Serial.print("Failed to connect, rc=");
			Serial.print(client.state());
			delay(2000);
                        #endif
		}
	}
}

void temp_ds () 
{
  if (flag_ds==DStime)
  {
    DS18B20.requestTemperatures(); 
    temp = DS18B20.getTempCByIndex(0);
    #ifdef debug
    Serial.print("Temperature DS18B20: ");
    Serial.println(temp);
    #endif
    
    char buffer[10];
    dtostrf(temp,0, 0, buffer);
    client.publish(outTopic6,buffer);
    
    
    flag_ds=0;
  }
}

void temp_hum()
{
  if (flag_th==DHTtime)
  {
    sensors_event_t event;
    dht.temperature().getEvent(&event);
    
    if (isnan(event.temperature))
    {
      #ifdef debug
      Serial.println("Error reading temperature!");
      #endif
    }
    else
    {
		temperature=event.temperature;
                #ifdef debug
                Serial.print("Temperature DHT11: ");
                Serial.println(temperature);
                #endif
	}

	dht.humidity().getEvent(&event);

    if (isnan(event.relative_humidity))
	{
		#ifdef debug
		Serial.println("Error reading humidity!");
		#endif
	}
	else
	{
		humidity=event.relative_humidity;
                #ifdef debug
                Serial.print("Humidity DHT11: ");
                Serial.println(humidity);
                #endif
	}

    //Float to char conversion and sending massage to MQTT broker
    char buffer[10];
    dtostrf(temperature,0, 0, buffer);
    client.publish(outTopic1,buffer);
    dtostrf(humidity,0, 0, buffer);
    client.publish(outTopic2,buffer);
    flag_th=0;
  }
}
        
void motionsensor()
    {
      state_MS=digitalRead(MSPIN);
	if (state_MS==HIGH && prev_state_MS==LOW)
	{
		#ifdef debug
		Serial.println("motion");
		#endif
		client.publish(outTopic3,"triggered");
	}
        else 
        {
          if (flag_motion==Motiontime)
          {
            Serial.println("motionDISARMED");
            client.publish(outTopic3,"disarmed");
            flag_motion=0;
          }
        }
	prev_state_MS=state_MS;
    }

void MQ2alarm()
    {
      state_MQ2 = digitalRead(MQ2PIN);
	if (state_MQ2==HIGH && prev_state_MQ2==LOW)
	{
		#ifdef debug
		Serial.println("ALARM");
		#endif
		client.publish(outTopic4,"triggered");
	}
prev_state_MQ2=state_MQ2;
    }
      
      
void reed ()
    {
      if (digitalRead (REEDPIN) && flag_reed)
        {
          reed_counter++;
           
          if (reed_counter==2)
          {
            client.publish(outTopic5,"triggered");
            #ifdef debug
            Serial.println("doors open");
            #endif
            reed_counter=0;
             }
          flag_reed=0;
        }
        else if (!digitalRead (REEDPIN))
        {
          
          client.publish(outTopic5,"disarmed");
            #ifdef debug
            Serial.println("doors closed");
            #endif
          reed_counter=0;
          
        }
    }
void setup()
{
        delay(10);
	noInterrupts();

	//Baud rate
	Serial.begin(115200);

	//Configuring mqtt server (ip, port)
	client.setServer(mqtt_server, 1883);

	//PIN configuration
	pinMode(DHTPIN,INPUT);
	pinMode(MSPIN,INPUT);
	pinMode(MQ2PIN,INPUT);
        pinMode(REEDPIN,INPUT);
        pinMode(REEDOUT,OUTPUT);
        digitalWrite(REEDOUT, LOW);

        prev_state_MQ2 = !digitalRead(MQ2PIN);
        
	//Wifi setup
	//setup_wifi();

	//Configuration of DHT sensor
	dht.begin();

	//Interrupt configuration
	timer0_isr_init();
	timer0_attachInterrupt(timer_interrupt);
	timer0_write(ESP.getCycleCount() + 80000000);

	interrupts();
}

void loop()
{
  	
  //Keeping Wifi connection
	if (WiFi.status() != WL_CONNECTED)
	{
		setup_wifi();
	}
	//keeping MQTT connection
	if (!client.connected())
	  {
		mqttconnection();
	  } 

        #ifdef DHT_11
        temp_hum();
        #endif
        
        #ifdef DS_18B20
        temp_ds();
        #endif
         
        #ifdef PIR 
        motionsensor();
        #endif
        
        #ifdef MQ2
        MQ2alarm();
        #endif
         
        #ifdef REEDRELAY 
        reed();
        #endif
                    
}

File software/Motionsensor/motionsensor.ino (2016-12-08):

#define debug
#define MSPIN             4					 // PIN connected to  motion sensor

const char* outTopic3 = "MS";

int state_MS;
int prev_state_MS;

void setup() 
    {
        pinMode(MSPIN,INPUT);
    }

void loop() 
  {
        state_MS=digitalRead(MSPIN);
	if (state_MS==HIGH && prev_state_MS==LOW)
	{
		#ifdef debug
		Serial.println("Motion detected");
		#endif
		client.publish(outTopic3,"Motion detected");
	}
	prev_state_MS=state_MS;
	delay (300);
  }

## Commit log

2016-11-28 PCB shield schematic for Raspberry Pi 3
2016-11-28 Raspberry Pi 3 gpio pinout
2016-11-28 Raspberry Pi 3 gpio pinout new version
2016-11-29 Big red button Python script
2016-11-30 ESP8266 configuration, code connecting to raspberry using wifi and mqtt
2016-11-30 DHT11 temperature and humidity sensor code
2016-11-30 Delete PCBv2.pdf
    Update to newer version
2016-11-30 Motion sensor - schematic
2016-12-05 New buttonscript's version
2016-12-08 Raspberry Pi 3 shield
2016-12-08 Description for Raspberry Pi 3 shield
2016-12-08 Sensors' schematic
2017-01-06 Add files via upload
    Bash script which is meant to install both mqtt and homeassistant. When using this you can skip whole installation. You can use this only after you are done with Raspbian configuration.
    To run simply navigate in terminal to skrypt.sh on your Raspberry PI and type "sudo bash skrypt.sh" After this you should have mqtt and homeassistant installed. Use readme to verify if everything was installed correctly.
2017-06-05 Kuba's innovations
    [power_control_system.brd, power_control_system.sch]
2017-06-05 Kuba's file
    [sterowanie_przekaźnik.brd, sterowanie_przekaźnik.sch]
2017-06-11 shield's update
    [Płytka_ESPv1.brd, Płytka_ESPv1.sch, Shield_v1.brd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]
2017-06-11 ESP shield v2
    [Płytka_ESPv2.brd, Płytka_ESPv2.sch]
2017-06-11 shield v2
    [Shield_v2.brd, Shield_v2.sch]
2017-06-23 ESPv3 shield
    [Płytka_ESPv3.brd, Płytka_ESPv3.sch]
2017-07-10 MQ2 and motion sensor message changed to "triggered"
2017-07-16 Files with scheme and PCB board for RPi shield
    [RPi_shield.brd, RPi_shield.sch]
2017-07-16 Files with scheme and PCB board for ESP8266
    [ESP8266.brd, ESP8266.sch]
